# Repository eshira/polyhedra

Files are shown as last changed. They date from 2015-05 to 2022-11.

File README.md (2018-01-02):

# polyhedra
Each of these files creates a tile.

The tiles have holes for magnets.

If correctly installed, the magnets guide the user to assembling the polyhedron properly.

Using magnets, as opposed to gluing, allows the user to assemble and disassemble the polyhedron repeatedly.

Also, the magnets distribute any errors in the tiles evenly, so that they do not accumulate and become obvious (which happens with gluing)

Another idea is to omit the magnets and use velcro instead. This seems especially suitable for the creation of large, foam versions of these tiles that could be cut using a jig. (if you make one, please send a picture! I'd love to see it)

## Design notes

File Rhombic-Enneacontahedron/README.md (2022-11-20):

## Rhombic Enneacontahedron

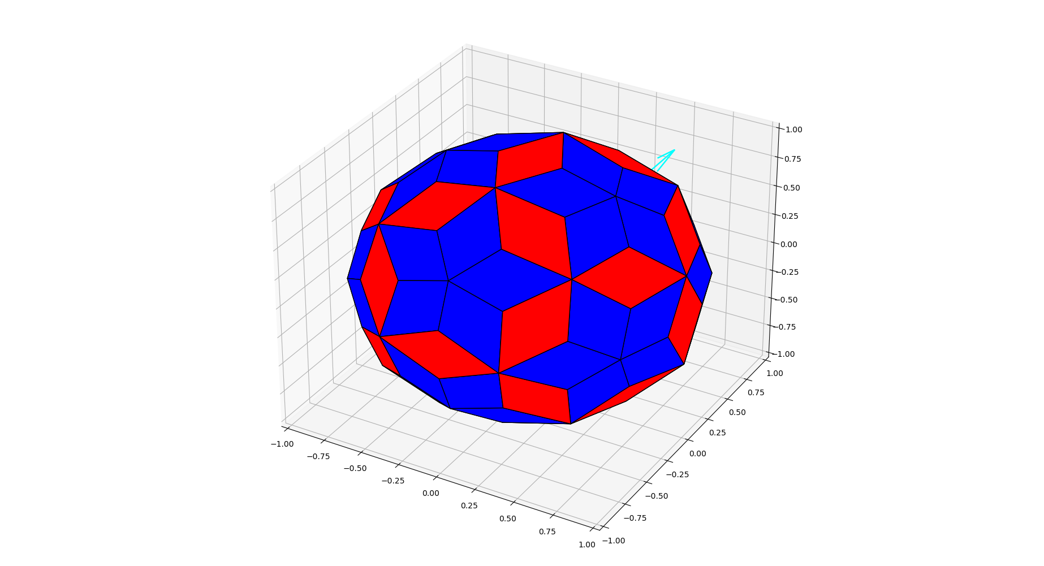
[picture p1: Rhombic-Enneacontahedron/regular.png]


### Using the testshape.py script:
Use ```testshape.py``` to calculate the angles needed by the OpenSCAD.
This generates a preview using library ```pyny3d``` which you will likely need to install.

There is a degree of freedom in the truncation step, controlled by the ```ALONG_EDGE``` parameter. Setting it to 3 splits one of the edges into 3 equal parts and creates the regular rhombic enneacontahedron shown above. If you set it to a negligible value above 2, it will result in a dodecahron (all blue tiles; red tiles become very small).

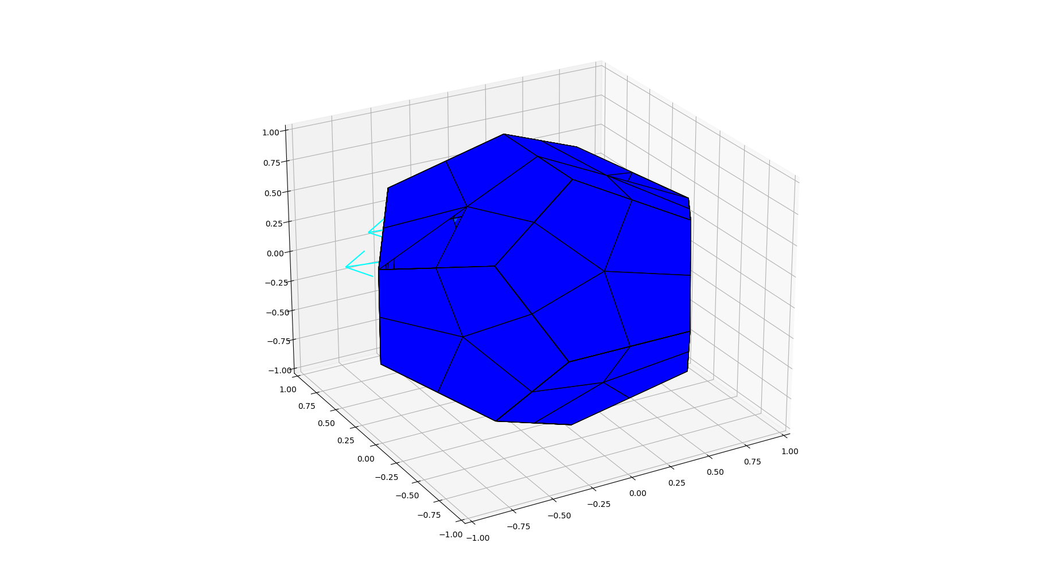
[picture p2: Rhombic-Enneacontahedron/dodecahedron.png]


If you set it to a very large value it will start to resemble a rhombic triacontahedron (all red tiles; blue tiles become very small).

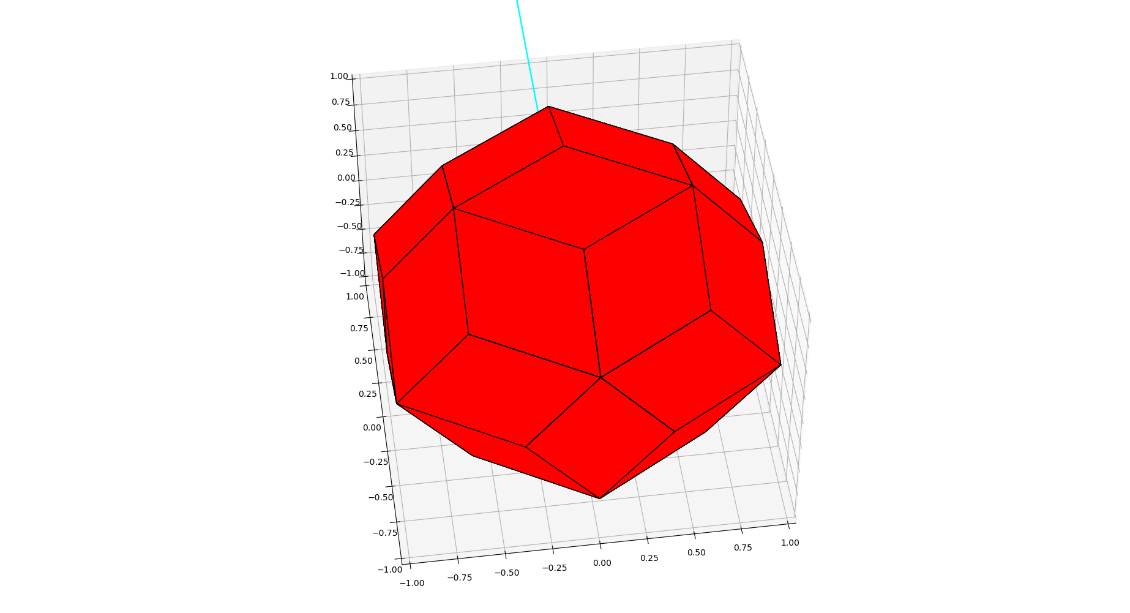
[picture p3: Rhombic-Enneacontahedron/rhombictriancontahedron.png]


You can use OpenSCAD file ```tilesAandB.scad``` to generate the tiles. See instructions below.

(Note: The older files, named ```rhombicenneacontahedronA.scad``` and ```rhombicenneacontahedronB.scad``` were designed for only the regular rhombic enneacontahedron with "regular" truncation into three pieces that corresponds to setting ```ALONG_EDGE=3``` in the python script)

### Using the OpenSCAD script:
Decide on the size and thickness of the tiles and the magnet holes depth and diameter in the "User Defined Variables" section. Units are millimeters.
```
//User Defined Variables
side = 30; //side length, these match to red side length
thickness = 8; //how thick (z dimension) the tile is
magnetdepth = 2.25; //depth of the magnet holes; tailor this to suit your 3d printer
magnetdiam = 4.45; //diameter of the magnet holes; tailor this to suit your 3d printer
```

Take the angles from the ```testshape.py``` script and paste them over the "Other Variables" section in the ```tilesAandB.scad``` file.
For example, for a regular rhombic enneacontahedron with "regular" truncation into three pieces that corresponds to setting ```ALONG_EDGE=3```:

```
//Other Variables - Get from python script
dihedral2= 159.4455573432933 ;
dihedral= 160.81186354627906 ;
alpha= 56.67993474152847 ;
beta= 69.73165195317623 ;
blue1b= 56.679934741528456 ;
obtuse= 116.79420665264766 ;
sidefactor= 0.830397632781982 ;
```
Don't update the block after that (calculating variables such as ```short```,```phi```,...```ldiag```). Those are calculated off the variables above.

Finally, choose what to render. Choose ```tile_A()``` to generate a "red" tile (shown below on the left). Choose ```tile_B()``` to generate a "blue" tile (shown below on the right).

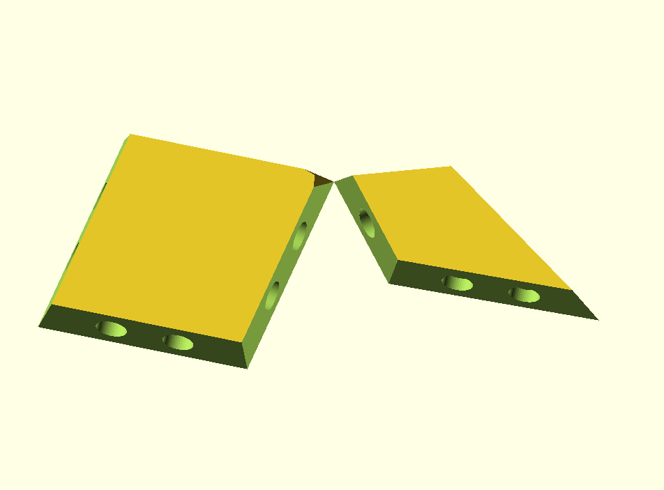
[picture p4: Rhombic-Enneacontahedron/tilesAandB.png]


Or choose ```unit()``` to generate an assembly of both (note it doesn't fold up perfectly--there's a small error from an angle I estimated instead of calculated). Note in the image below, for an ```ALONG_EDGE=4``` parameter and a very thick tile, the need to "bevel" the point where the three A tiles meet becomes more obvious. This bevel is needed for tiles where ```ALONG_EDGE```>3

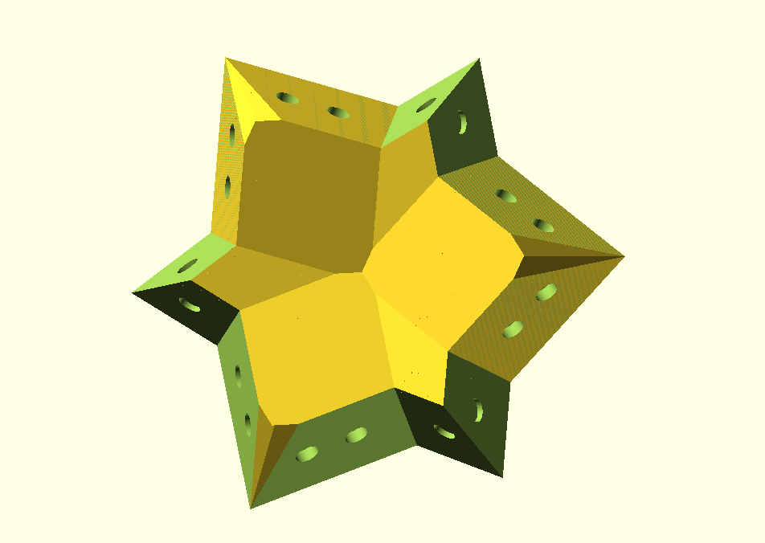
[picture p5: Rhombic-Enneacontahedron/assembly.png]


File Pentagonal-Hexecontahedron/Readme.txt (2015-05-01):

Playing around with a tile piece to create a Pentagonal hexecontahedron

http://en.wikipedia.org/wiki/Pentagonal_hexecontahedron

Catalan solid
Dual of snub dodecahedron

60 faces (irregular pentagon)
150 edges
92 vertices

Dihedral angle: 153 degrees 10' 43"

File is a mess (openscad is not friendly to this sort of thing)

Ideas:
3d print in different colors
Decoupage outside or paint
Mill out of wood with a v-carve bit matching the needed angle (probably would have to be custom)

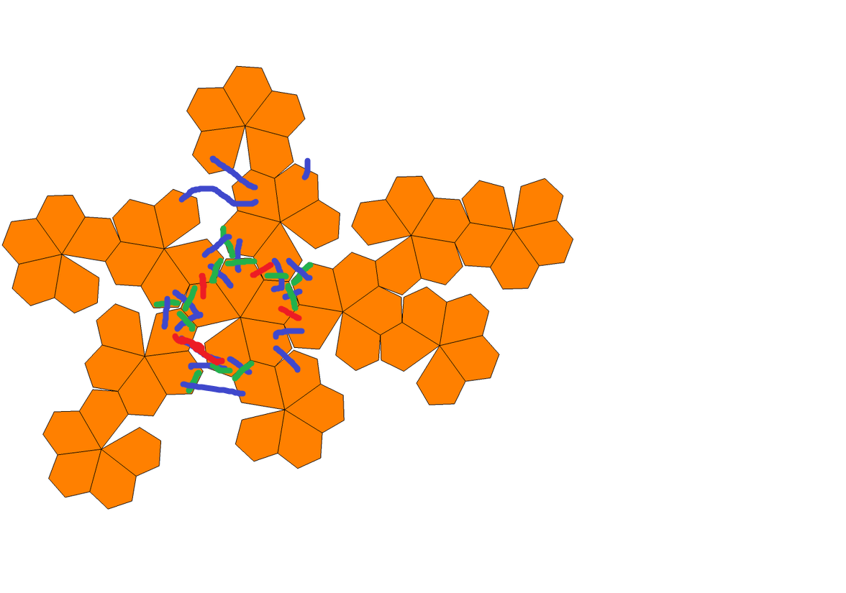
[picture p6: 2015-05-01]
Pentagonal-Hexecontahedron/magnetdiagram.png

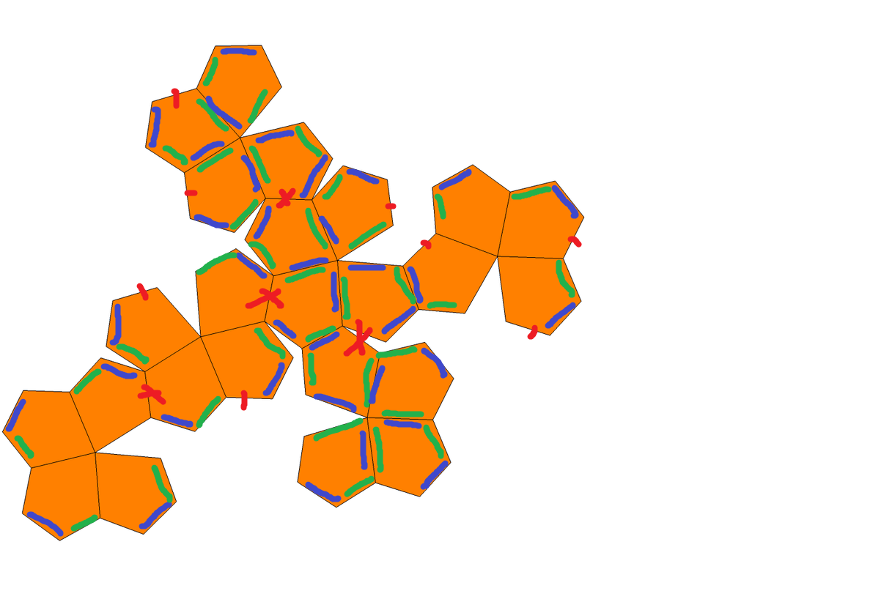
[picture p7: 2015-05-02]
Pentagonal-Icositetrahedron/magnetdiagram.png

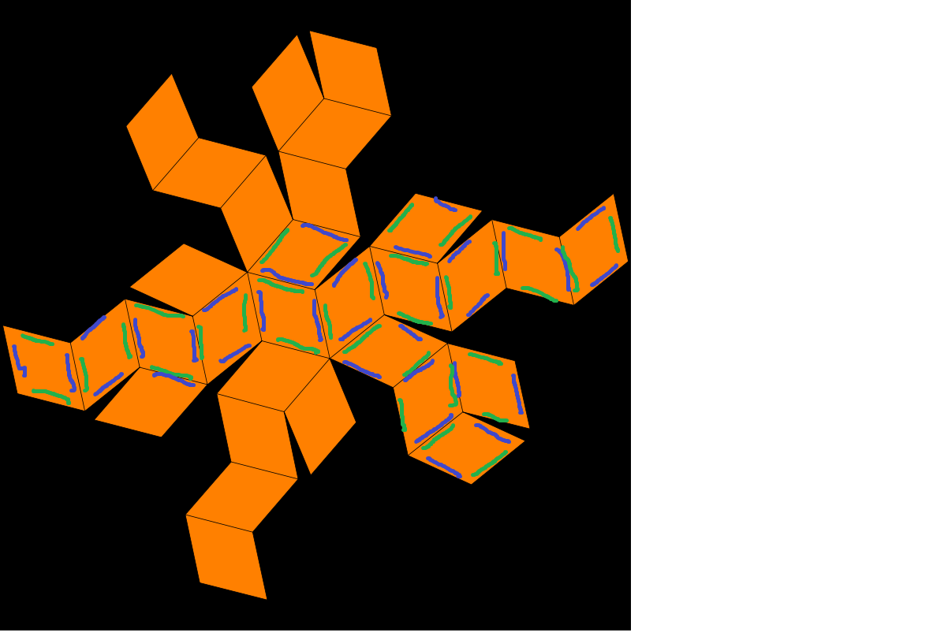
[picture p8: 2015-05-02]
Rhombic-Triacontahedron/magnetismdiagram.png

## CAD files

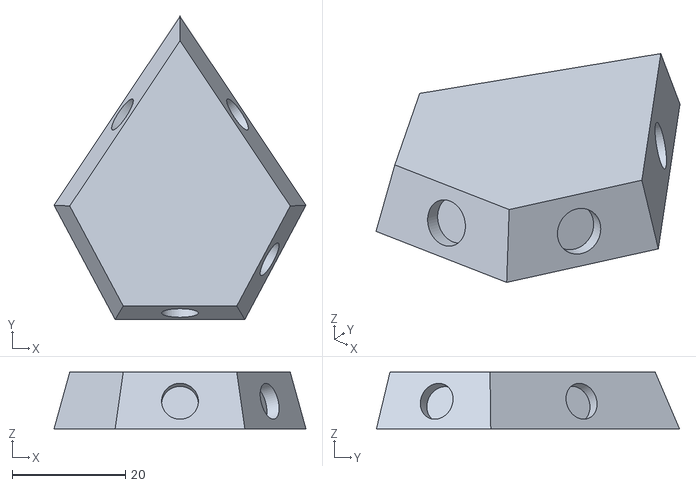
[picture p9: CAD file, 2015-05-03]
Pentagonal-Hexecontahedron/pentagonalhex.stl
44.4 x 53.4 x 10.0

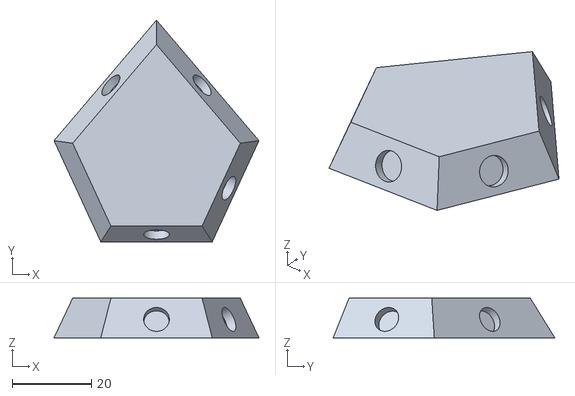
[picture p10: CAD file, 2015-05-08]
Pentagonal-Icositetrahedron/pentagonalicositetrahedron.stl
51.8 x 56.0 x 10.0

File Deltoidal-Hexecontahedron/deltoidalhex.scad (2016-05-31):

/*
	Deltoidal hexecontahedron with magnets tile, by eshira
	Dihedral angle: 154.12°
	
	60 tiles total are required.
	Use axially aligned magnets (4 per tile).
	Magnet mounting per tile MUST BE IDENTICAL!
	Following the following constraints:
		-Two parallel sides have the same pole facing outward
		-Two adjacent sides have the opposite pole facing outward
    See the diagram included for more help.

*/

$fn=50;

//User Defined Variables
longside = 40; //side length for longer side
thickness = 10; //how thick (z dimension) the tile is
magnetdepth = 2.5; //depth of the magnet holes; tailor this to suit your 3d printer
magnetdiam = 6.5; //diameter of the magnet holes; tailor this to suit your 3d printer

//Other Variables
dihedral = 154.12; //dihedral angle
phi = 118.22/2; // Half the angle between the two short sides
theta = 87.01; //Angle between long and short sides
shortside = longside*6/(7+sqrt(5)); //short side to long side ratio is 6:(7+√5)
ldiag = longside*sin(theta)/sin(phi); //Long diagonal of kite

//Main
tile();

//Modules
module tile() {
    difference(){
        mainbody();
        union(){
            chamfers();
            magnets();
        }
    }
}

module mainbody(){
	linear_extrude(height = thickness ) {
        polygon([[0,0],[-shortside*cos(90-phi),shortside*sin(90-phi)],[0,ldiag],[shortside*cos(90-phi),shortside*sin(90-phi)]]);
	}
}

module chamfers() {
	rotate([(180-dihedral)/2,0,phi+90]){
		linear_extrude(center=true, height=thickness*10) {
			polygon([[-5,0],[-5,thickness],[shortside+5,thickness],[shortside+5,0]]);
		}
	}
    
    mirror([1,0,0]){
        rotate([(180-dihedral)/2,0,phi+90]){
            linear_extrude(center=true, height=thickness*10) {
                polygon([[-5,0],[-5,thickness],[shortside+5,thickness],[shortside+5,0]]);
            }
        }
    }
    translate([0,ldiag,0]){
    	rotate([(180-dihedral)/2,0,-phi-theta+90]){
            linear_extrude(center=true, height=thickness*10) {
                polygon([[-5,0],[-5,thickness],[longside+5,thickness],[longside+5,0]]);
            }
        }
    }
    
    mirror([1,0,0]){
        translate([0,ldiag,0]){
            rotate([(180-dihedral)/2,0,-phi-theta+90]){
                linear_extrude(center=true, height=thickness*10) {
                    polygon([[-5,0],[-5,thickness],[longside+5,thickness],[longside+5,0]]);
                }
            }
        }
    }
}

module magnets() {
    extra=0.1;
    
    translate([-0.5*shortside*cos(90-phi),0.5*shortside*sin(90-phi),0]){
        rotate([180-dihedral/2,0,phi+90]){
            translate([0,thickness/2,-extra]) {
                linear_extrude(center=false, height=magnetdepth) {
                    circle(magnetdiam/2);
                }
            }
        }
    }
    
    mirror([1,0,0]){
        translate([-0.5*shortside*cos(90-phi),0.5*shortside*sin(90-phi),0]){
            rotate([180-dihedral/2,0,phi+90]){
                translate([0,thickness/2,-extra]) {
                    linear_extrude(center=false, height=magnetdepth) {
                        circle(magnetdiam/2);
                    }
                }
            }
        }
    }
    
    mirror([0,0,0]){
        translate([0.5*longside*cos(theta-(180-2*phi)/2),0.5*longside*sin(theta-(180-2*phi)/2)+shortside*sin(90-phi),0]){
            rotate([180-dihedral/2,0,-90+theta/2]){
                translate([0,thickness/2,-extra]) {
                    linear_extrude(center=false, height=magnetdepth) {
                        circle(magnetdiam/2);
                    }
                }
            }
        }
    }    
    
    mirror([1,0,0]){
        translate([0.5*longside*cos(theta-(180-2*phi)/2),0.5*longside*sin(theta-(180-2*phi)/2)+shortside*sin(90-phi),0]){
            rotate([180-dihedral/2,0,-90+theta/2]){
                translate([0,thickness/2,-extra]) {
                    linear_extrude(center=false, height=magnetdepth) {
                        circle(magnetdiam/2);
                    }
                }
            }
        }
    } 
}

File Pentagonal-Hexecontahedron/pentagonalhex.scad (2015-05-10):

/*
	Pentagonal hexecontahedron with magnets tile, by eshira
	Dihedral angle: 153.1786°
	Pentagonal angles: 118.14° (4), 67.44°(1)
	This shape has a chirality (left/right handedness)
	To make the other enantiomorph, take the mirror of this tile instead
	
	60 tiles total are required.
	Use axially aligned magnets (4 per tile).
	Magnet mounting per tile MUST BE IDENTICAL!
	Following the following constraints:
		-The two long sides of the pentagon should have opposite poles facing outward
		-The two short sides with holes should have opposite poles facing outward

	For example, you could do N - S - N - S going around the pentagon, skipping the empty face.

*/

$fn=50;

//User Defined Variables
longside = 40; //long side length of the pentagon
thickness = 10; //how thick (z dimension) the tile is
magnetdepth = 2.5; //depth of the magnet holes; tailor this to suit your 3d printer
magnetdiam = 6.5; //diameter of the magnet holes; tailor this to suit your 3d printer

//Other Variables
dihedral = 153.1786; //the dihedral angle
alpha = 67.44; //pentagon small inner angle (1)
beta = 118.14; //pentagon large inner angle (4)
b = sin(alpha/2)*longside;
a = cos(alpha/2)*longside;
gamma = asin(a/longside);
shortside = 2*b/(1+2*cos(beta-gamma)); //short side length of pentagon
c = sin(beta-gamma)*shortside;
d = thickness/tan(dihedral/2);
e = sin(180-beta)*thickness;
f = sqrt(thickness*thickness-e*e);


//Main Code
difference(){
	mainbody();
		union(){
		chamfers();
		magnets();}
}


//Modules

module mainbody(){
	linear_extrude(height = thickness ) {
		polygon([[0,0],[+b,-a],[shortside/2,-a-c],[-shortside/2,-a-c],[-b,-a]]);
	}
}

module chamfers() {
	rotate([(180-dihedral)/2,0,-90+alpha/2]){
		linear_extrude(center=true, height=25) {
			polygon([[-5,0],[-5,thickness],[longside+5,thickness],[longside+5,0]]);
		}
	}

	rotate([(180-dihedral)/2,0,90-alpha/2]){
		mirror([1,0,0]){
			linear_extrude(center=false, height=25) {
				polygon([[-5,0],[-5,thickness],[longside+5,thickness],[longside+5,0]]);
			}
		}
	}

	translate([(shortside/2),-a-c,0]){
		rotate([(-180+dihedral)/2,0,180-beta]){
			translate([0,-thickness,0]){
				linear_extrude(center=true, height=25) {
					polygon([[-5,0],[-5,thickness],[shortside,thickness],[shortside,0]]);
				}
			}
		}
	}

	mirror([1,0,0]){
		translate([(shortside/2),-a-c,0]){
			rotate([(-180+dihedral)/2,0,180-beta]){
				translate([0,-thickness,0]){
					linear_extrude(center=true, height=25) {
						polygon([[-5,0],[-5,thickness],[shortside,thickness],[shortside,0]]);
					}
				}
			}
		}
	}

	translate([0,-a-c,0]){
		rotate([(-180+dihedral)/2,0,0]){
			linear_extrude(center=true, height=25) {
				polygon([[-shortside/2,-thickness],[shortside/2,-thickness],[shortside/2,0],[-shortside/2,0]]);
			}
		}
	}
}

module magnets() {
	rotate([-dihedral/2,0,-90+alpha/2]){
		translate([longside/2,-thickness/2,-magnetdepth+0.2]){
			linear_extrude(center=false, height=magnetdepth+0.2) {
				circle(magnetdiam/2);
			}
		}
	}

	mirror([1,0,0]){
		rotate([-dihedral/2,0,-90+alpha/2]){
			translate([longside/2,-thickness/2,-magnetdepth+0.2]){
				linear_extrude(center=false, height=magnetdepth+0.2) {
					circle(magnetdiam/2);
				}
			}
		}
	}

	translate([(shortside/2),-a-c,0]){
		rotate([(-180+dihedral)/2,0,180-beta]){
			rotate([-90,0,0]){//90-dihedral
				translate([shortside/2,-thickness/2,-.2]){
					linear_extrude(center=false, height=magnetdepth+0.2) {
						circle(magnetdiam/2);
					}
				}
			}
		}
	}

	translate([0,-a-c,0]){
		rotate([(-180+dihedral)/2,0,0]){
			translate([0,magnetdepth-.2,thickness/2]){
				rotate([90,0,0]){
					linear_extrude(center=false, height=magnetdepth+0.2) {
						circle(magnetdiam/2);
					}
				}
			}
		}
	}
}

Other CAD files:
Deltoidal-Icositetrahedron/deltoidalicosi.scad
Pentagonal-Icositetrahedron/pentagonalicositetrahedron.scad
Pyritohedra/pyritohedra.scad
Rhombic-Dodecahedron/rhombicdodecahedron.scad
Rhombic-Enneacontahedron/rhombicenneacontahedronA.scad
Rhombic-Enneacontahedron/rhombicenneacontahedronB.scad
Rhombic-Enneacontahedron/tilesAandB.scad
Rhombic-Triacontahedron/rhombictria.scad
Trapezohedra/trapezohedra.scad

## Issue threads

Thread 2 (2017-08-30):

Curious if you have issues with tolerance

jbum, 2017-08-30:
Hi Shira,

I was admiring your magnetic polyhedra.  I've been building some similar 3d printer shapes for very basic Dodecahedron and Icosahedrons (to start), and simply glueing them together with Silicon.  I'm finding that, even though I believe I have the dihedral angles correct, my pieces tend to accumulate a lot of tolerance error when joined together (e.g. after gluing 3 or 4 tiles, the 5th one is really janky.

I'm curious if you find that the magnets help distribute the error better.  I noticed in your openSCAD scripts, you seem to not be using any 'fudge factor' - I saw in your Pentagonal icositetrahedron, for example, that you had a variable called 'extra', but it was unused.  Curious if you encountered any tolerance issues...  You can contact me via email at jbum@jbum.com   Jim Bumgardner.

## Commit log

2015-05-01 Added Pentagonal Hexecontahedron project
    [pentagonalhex.scad, pentagonalhex.stl]
2015-05-01 Update to the rough magnet connectivity diagram
2015-05-01 Edited chamfer angles (needed to divide angle by 2)
    [pentagonalhex.scad]
2015-05-01 Updated sample STL to reflect changes to OpenSCAD file
    [pentagonalhex.stl]
2015-05-02 Added placeholders for additional good candidates for magnetic snap polyhedron pieces.
2015-05-02 Convoluted fix to change folder name case to match the rest
2015-05-03 Pentagonal Icositetrahedron added and magnet sizes adjusted for 3d printer
    [pentagonalhex.stl, pentagonalicositetrahedron.scad]
2015-05-08 Fixed problem with STL generation (not a valid manifold b/c of lack of overlap)
    [pentagonalicositetrahedron.scad, pentagonalicositetrahedron.stl]
2015-05-10 Cleaned up files in preparation for publication on Thingiverse
    [pentagonalhex.scad, pentagonalicositetrahedron.scad]
2016-05-27 Rhombic triacontahedron
    Added rhombic triacontahedron code, without magnets module for now.
    [rhombictria.scad]
2016-05-27 Added magnet holes
    Added magnet hole function.
    [rhombictria.scad]
2016-05-30 Deltoidal icositetrahedron
    Added kite shape and chamfers to deltoidal icositetrahedron. (no magnet
    holes yet)
    [deltoidalicosi.scad]
2016-05-30 Added magnet holes
    Added magnet holes to deltoidal icositetrahedron.
    [deltoidalicosi.scad]
2016-05-31 Added deltoidal hexecontahedron
    Added deltoidal hexecontahedron (just changed numbers from deltoidal
    icositetrahedron)
    [deltoidalhex.scad]
2017-01-09 Magnetholes fix
    Fixed a bug is the placement of the magnet holes and added some math in
    order to center the holes on the tile faces (aesthetic choice; holes do
    not have to be centered on a face in order to align with those on
    adjacent tiles).
    [rhombictria.scad]
2017-01-09 Added rhombic dodecahedron
    A simple set of changes from the Rhombic Triacontahedron to yield the
    Rhombic Dodecahedron.
    [rhombicdodecahedron.scad]
2017-03-10 Added trapezohedra
    [trapezohedra.scad]
2017-12-03 Initial exploration of pyritohedra series. Script creates the whole solid using the OpenSCAD polyhedron function.
    [pyritohedra.scad]
2017-12-06 Worked out dihedral angles (2 kinds) and started chamfering edges on tile
    [pyritohedra.scad]
2017-12-18 Magnet holes added to pyritohedra
    [pyritohedra.scad]
2017-12-19 Added an assembly of all the tiles to help verify result.
    [pyritohedra.scad]
2019-01-22 Added rhombic enneacontahedron; messy but better to commit than to wait. Python script to create overall solid, compute angles, and OpenSCAD scripts to generate the tiles
    [rhombicenneacontahedronA.scad, rhombicenneacontahedronB.scad]
2022-11-19 Added support to change the parameter of the truncation step. Reworked OpenSCAD file to support the tile A/red tiles for truncation step ALONG_EDGE parameter because for the non-default version, on t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
    [tilesAandB.scad]
2022-11-20 Forgot to add the bevel to the other side before.
    [tilesAandB.scad]
2022-11-22 Updated unit() in SCAD to generate the beveled tileAs and updated the assembly.png picture to match
    [tilesAandB.scad]
